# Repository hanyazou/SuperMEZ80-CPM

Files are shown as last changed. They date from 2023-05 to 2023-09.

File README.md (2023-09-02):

# SuperMEZ80-CPM
SuperMEZ80-CPM is a Z80 mezzanine board for simple single board computer EMUZ80.
SuperMEZ80-CPM adds SRAM and SPI micro SD Card slot to the EMUZ80.
With SuperMEZ80-CPM, you can run CP/M 2.2 and 3.0 disk images from the z80pack on the EMUZ80.

SuperMEZ80-CPM Features
  * Simple 3-chip configuration of Z80, SRAM and PIC
  * CP/M 3.0 banked memory can be used
  * A retro appearance, all chips are DIP, no surface-mounted components

SuperMEZ80-CPM is derived from satoshiokue's MEZ80RAM board.
Both EMUZ80 and MEZ80RAM are very interesting ideas.

SuperMEZ80-CPM is similar to the SuperMEZ80-SPI.
SuperMEZ80-CPM is simpler board with fewer components by removing I/O expander chip from SuperMEZ80-SPI.

## Appearance
The blue board in the following photo is SuperMEZ80-CPM and the red board is EMUZ80.





## Components you need

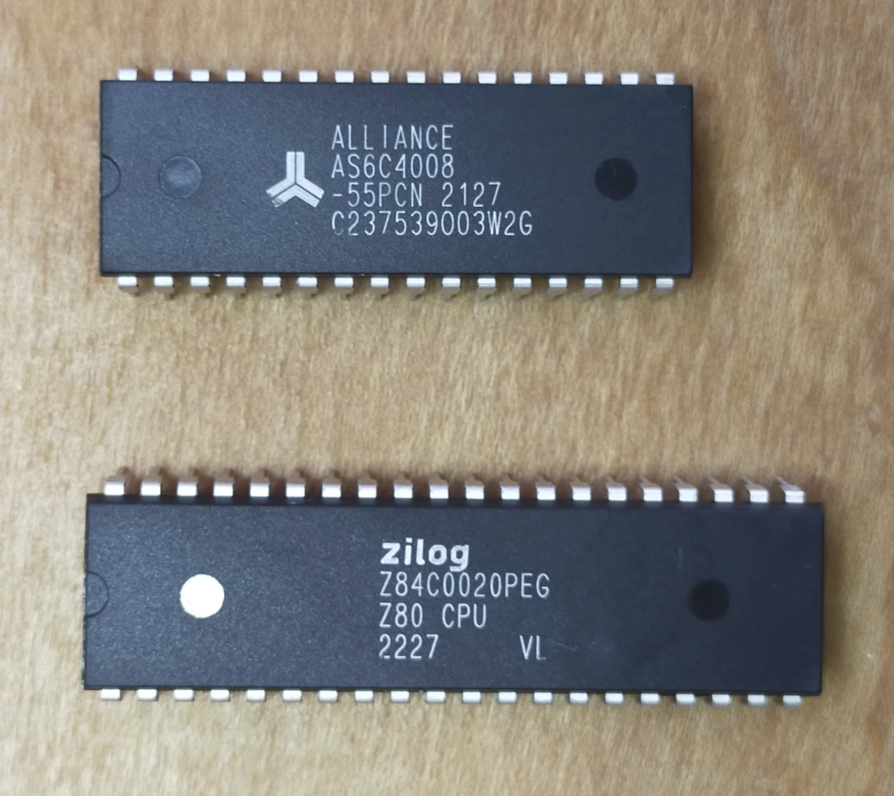
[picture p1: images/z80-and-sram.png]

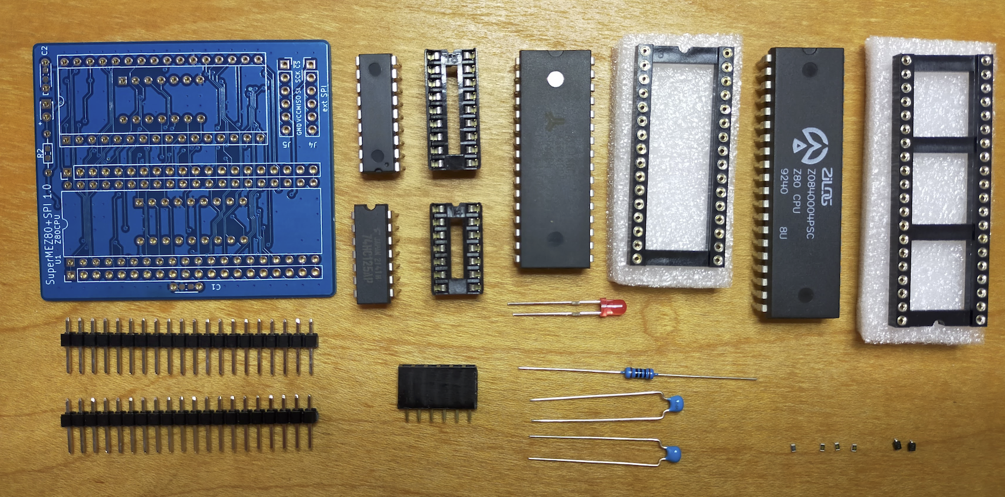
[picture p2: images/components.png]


### IC
  * 1 Z80 (DIP 40 pin) *1
  * 1 AS6C4008-55 SRAM 4Mbit (DIP 32 pin) *2
### Through hole components
  * 1 IC socket (DIP 40 pin)
  * 1 IC socket (DIP 32 pin)
  * 1 SD Card slot *3
  * 2 Capacitor 0.1uF
  * 3 LED
  * 3 Resistor 1.5K ohms 1/4W (the value of resistor will vary depending on the LED)
  * 1 Resistor array 10K ohms x8
  * 2 Pin header (0.1" pich 20x1 pin)
  * 1 Jumper cap and header (0.1" pich) *4
  * 1 Pin socket (0.1" pich 6x1 pin)

*1) Z80C0006 (6MHz) or higher are recomended

*2) 2Mbit (256KB) or more is required for CP/M 3.0.
CP/M 2.2 can still run with 512Kbit (64KB) or 1Mbit (128KB) RAM like TC551001.

*3) For the micro SD Card slot, use the one for Arduino as shown in the following page.

https://circuitdigest.com/microcontroller-projects/interfacing-micro-sd-card-module-with-arduino

*4) I use right angle pin header and jumper.
They are useful when I experiment external clock source. 
But you can omit them and just short RA3 - Z80 CLK with solder.

## Build Instructions

Due to some tall components, it is recommended to assemble them in the following order.

### Step 1: DIP 40 socket
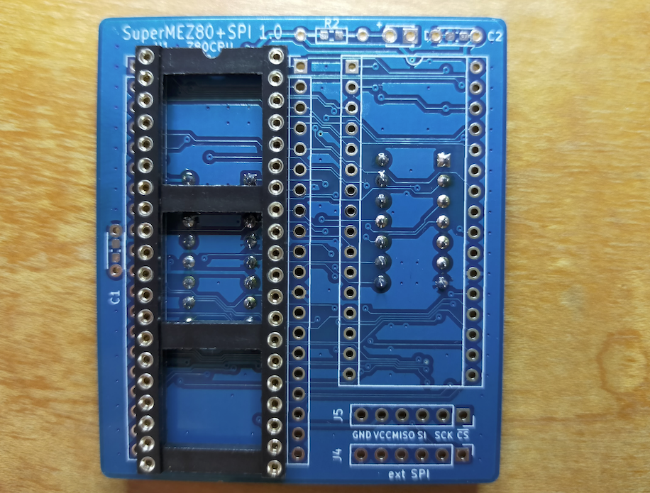
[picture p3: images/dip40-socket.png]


### Step 2: pin headers
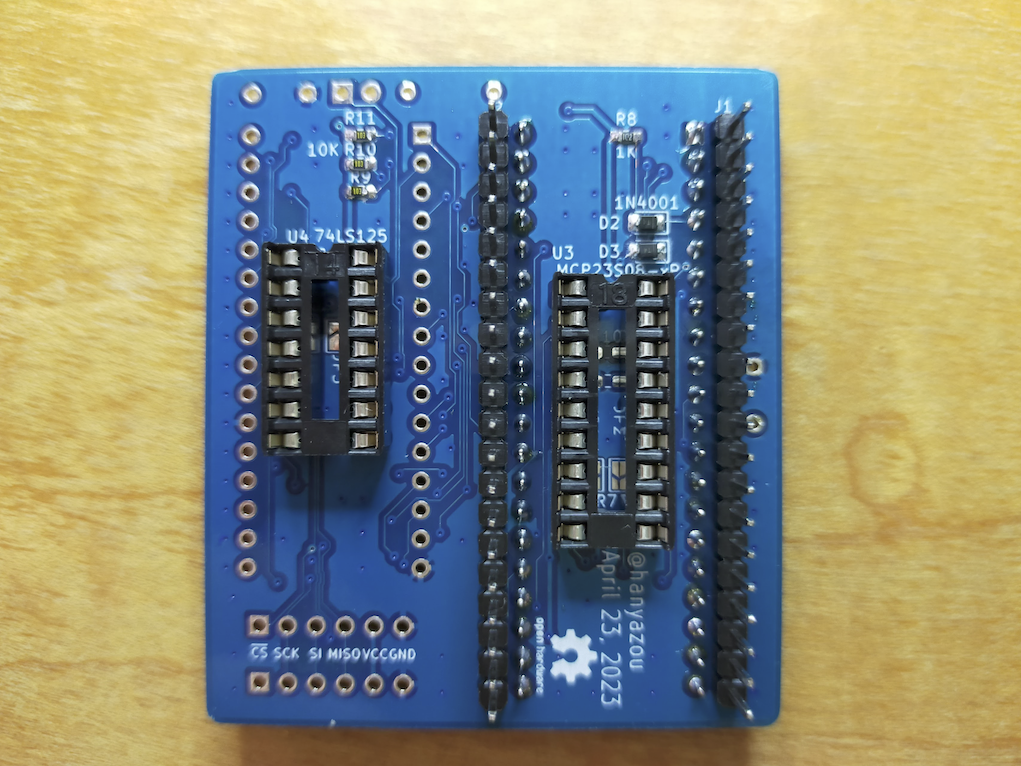
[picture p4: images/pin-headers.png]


### Step 3: LED and passive components


### Step 4: DIP 32 socket and 6 pin socket


## (Optional) SD card slot modification
SD Card slot component in the market may have a right angle pin header.
As it is, it might be little bit ugly as shown in the picture.



I de-soldered and replaced the header and mounted the SD card slot in back of SuperMEZ80-CPM.





You can also mount the SD Card slot on the top of the board like SuperMEZ-SPI.



## References
### SuperMEZ80 (derived version for SuperMEZ80-CPM)
Use this firmware to PIC on the EMUZ80 board.

https://github.com/hanyazou/SuperMEZ80

### EMUZ80
https://vintagechips.wordpress.com/2022/03/05/emuz80_reference/

### z80pack
https://github.com/udo-munk/z80pack

### MEZ80RAM
https://github.com/satoshiokue/MEZ80RAM

### SuperMEZ80 (Satoshi Okue's original FW for MEZ80RAM)
https://github.com/satoshiokue/SuperMEZ80

### SuperMEZ80-SPI
https://github.com/hanyazou/SuperMEZ80-SPI

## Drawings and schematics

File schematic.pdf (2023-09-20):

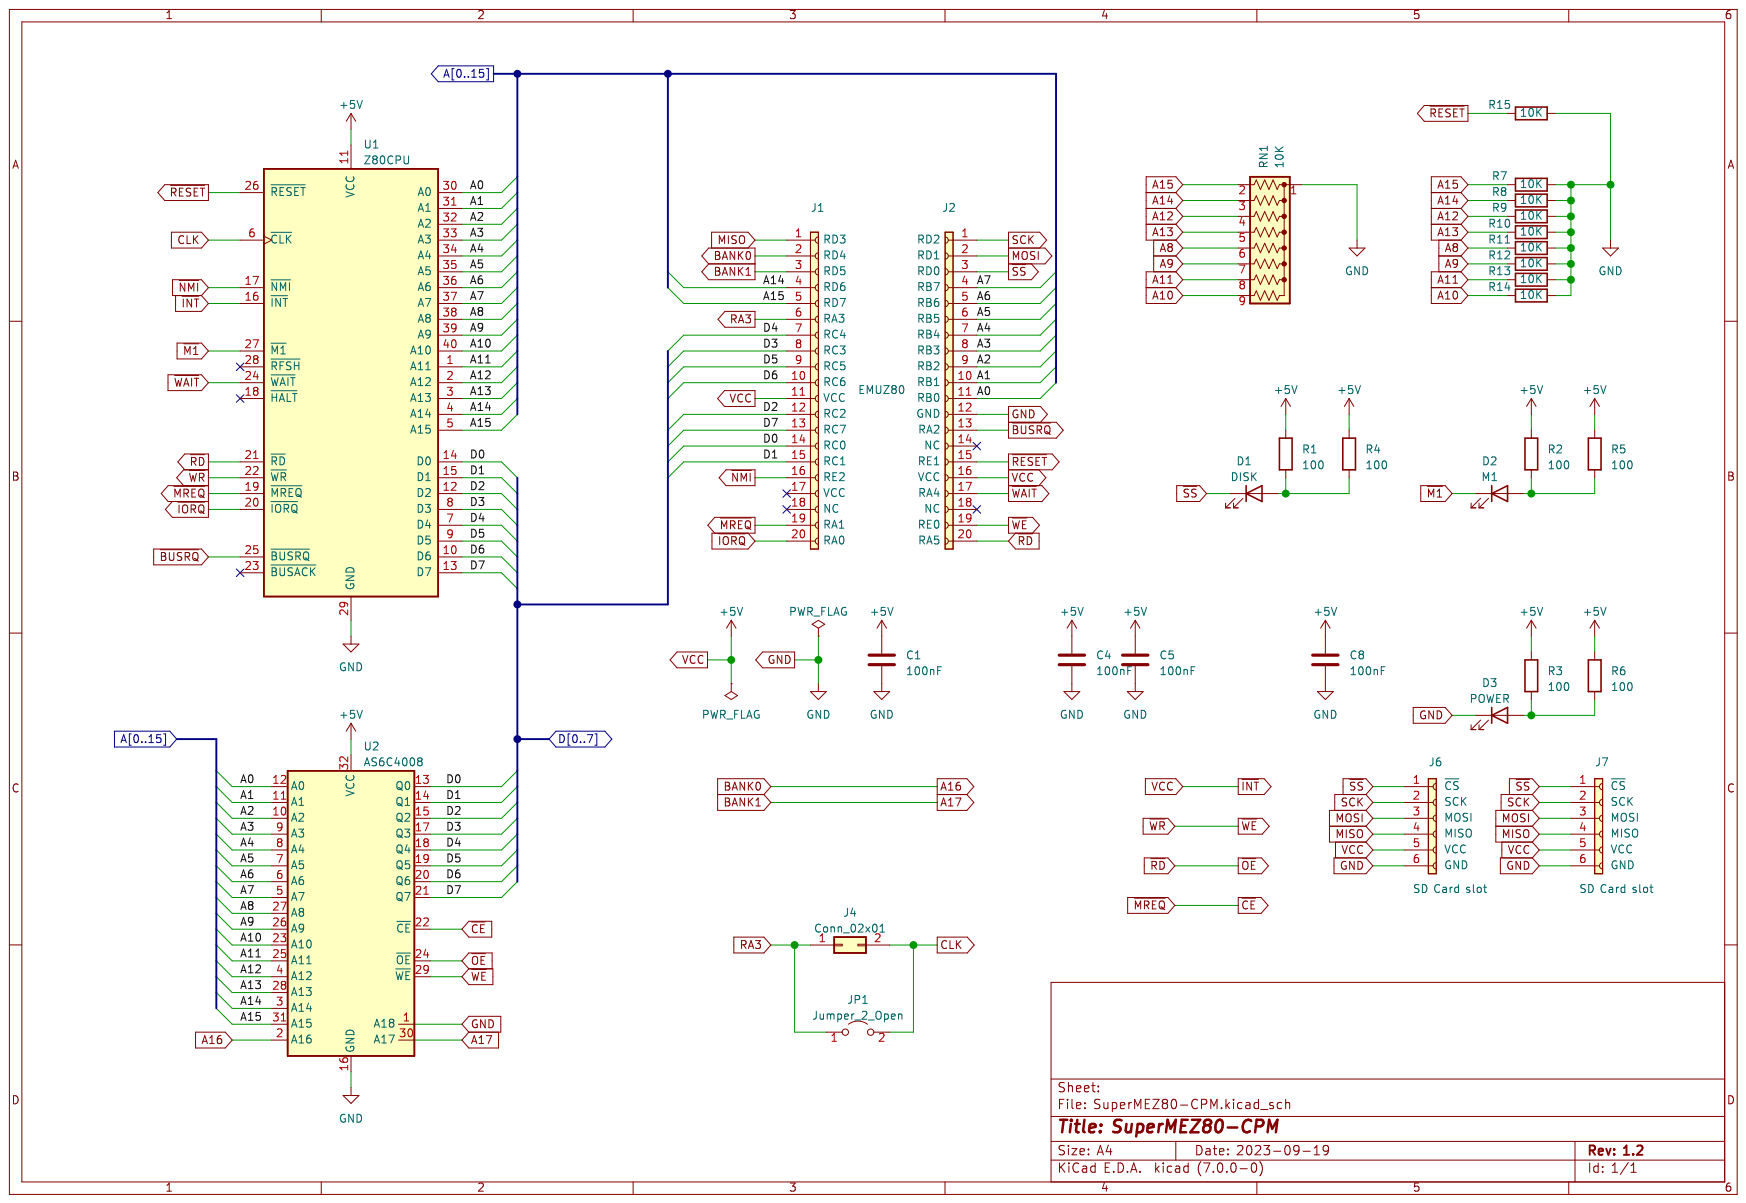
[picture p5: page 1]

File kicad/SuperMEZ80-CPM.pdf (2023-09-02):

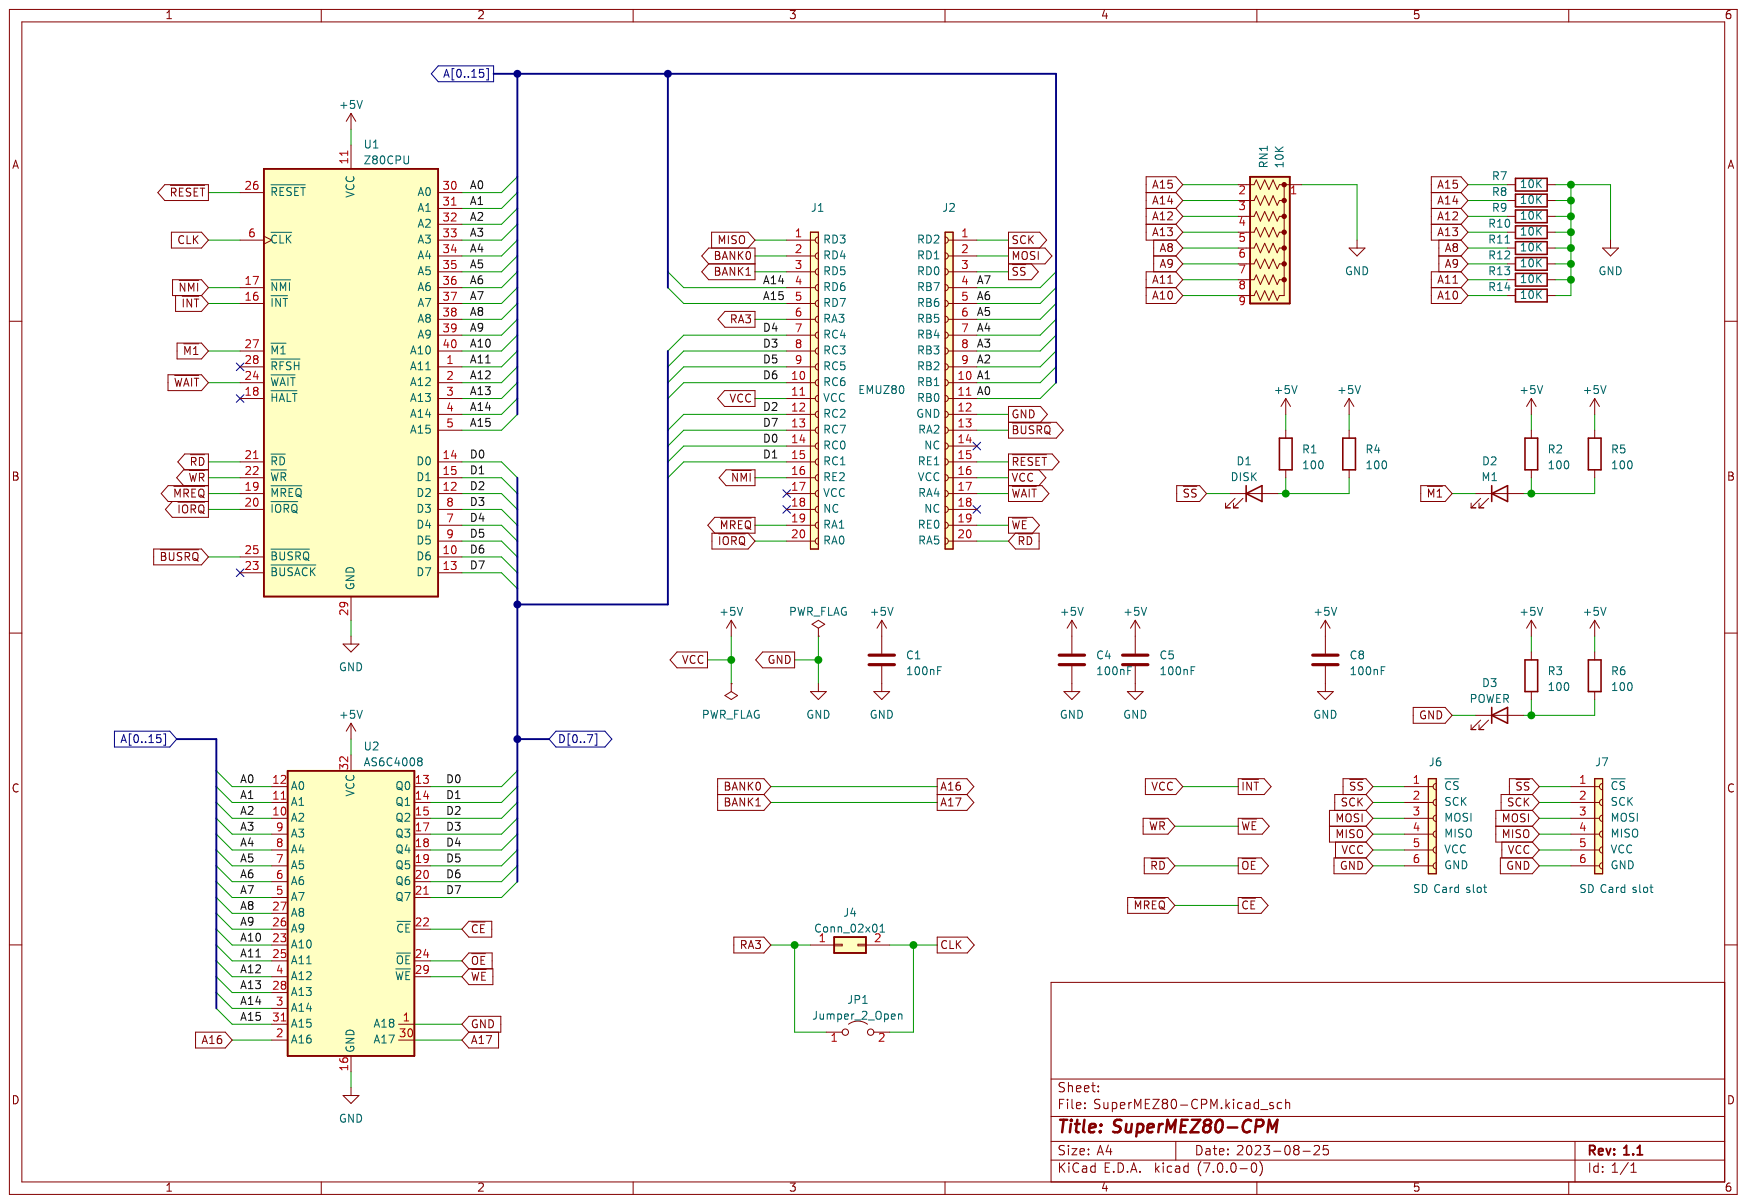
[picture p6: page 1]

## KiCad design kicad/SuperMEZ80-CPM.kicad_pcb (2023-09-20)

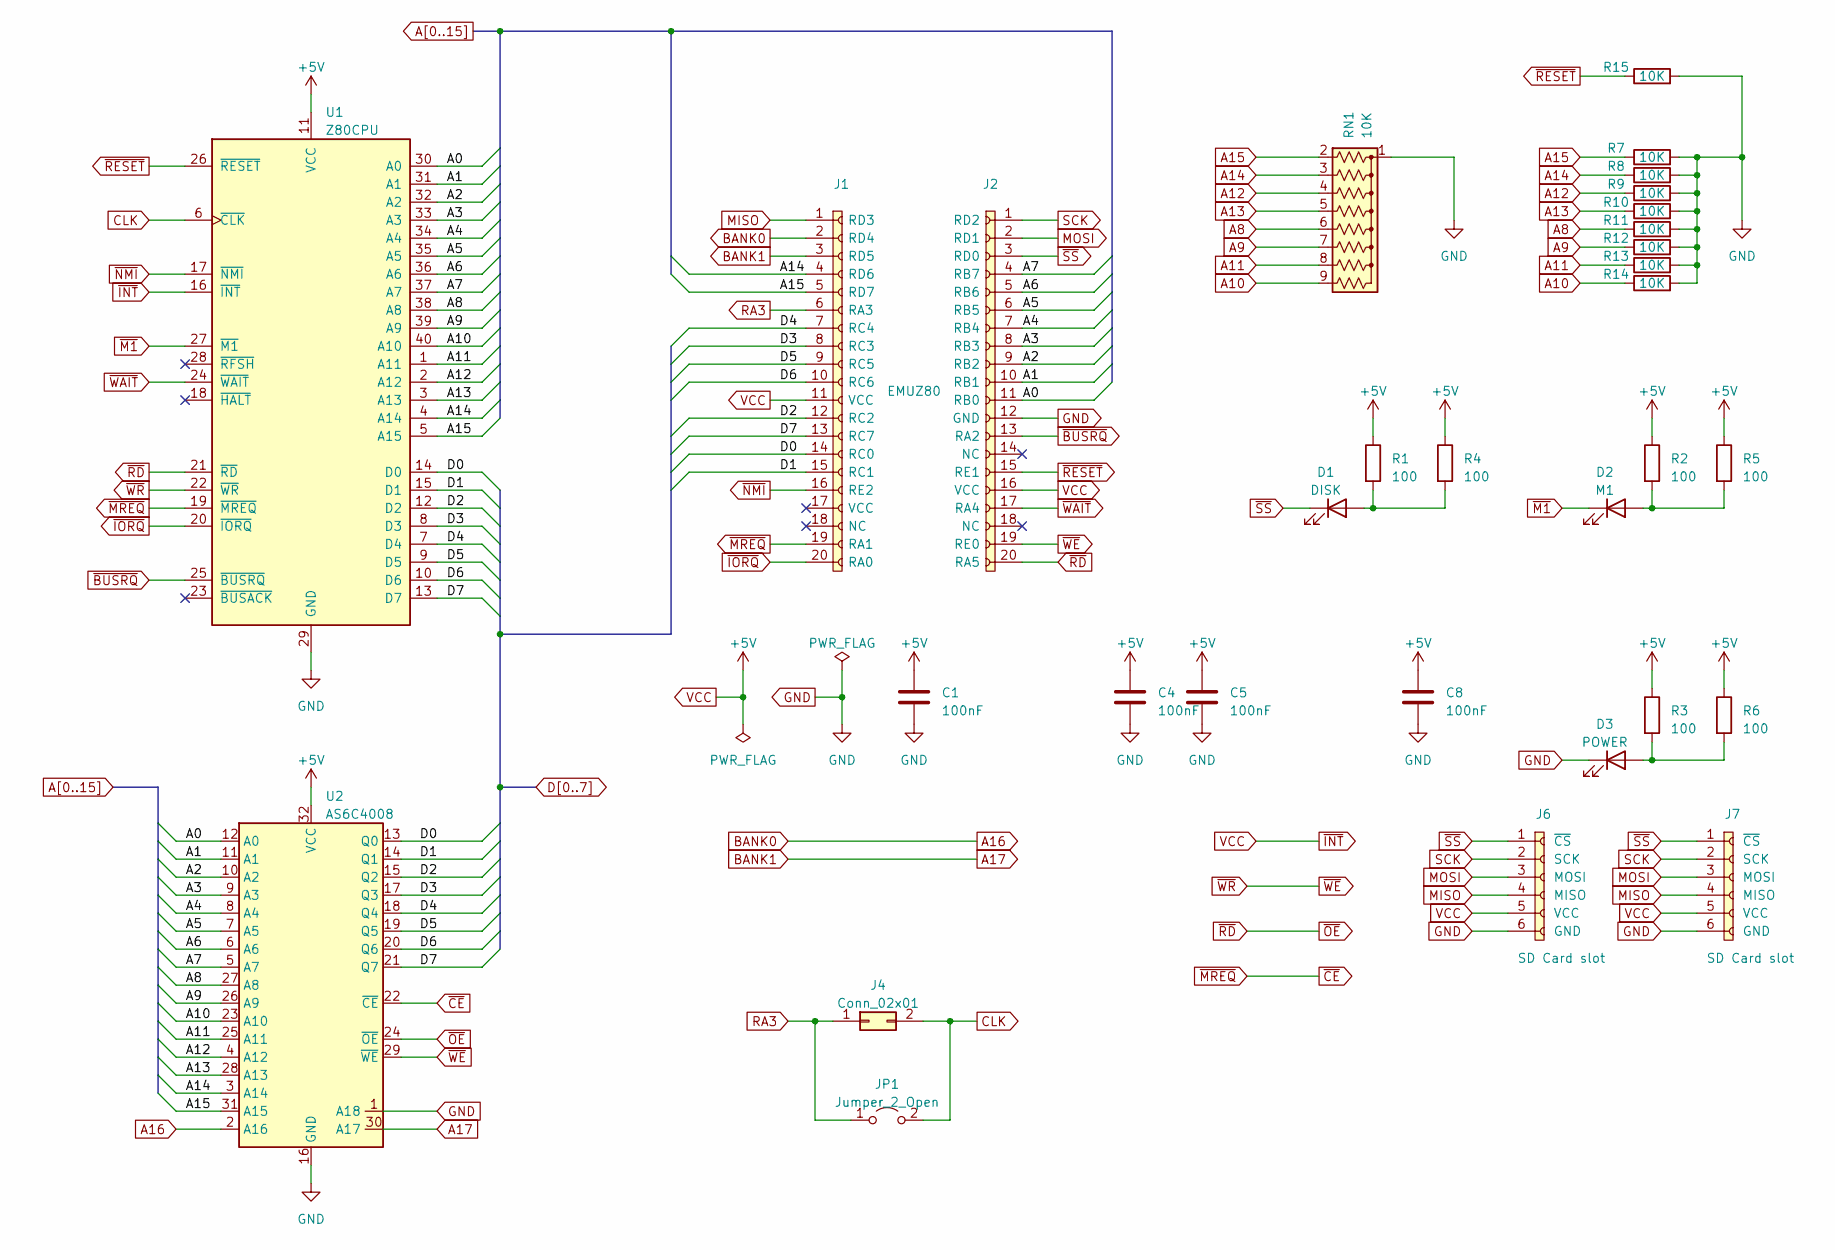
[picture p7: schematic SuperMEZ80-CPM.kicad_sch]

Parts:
C1, C4: 100nF; C_Disc_D4.3mm_W1.9mm_P5.00mm
C5, C8: 100nF; C_0603_1608Metric_Pad1.08x0.95mm_HandSolder
D1: DISK; LED_D1.8mm_W3.3mm_H2.4mm
D2: M1; LED_D1.8mm_W3.3mm_H2.4mm
D3: POWER; LED_D1.8mm_W3.3mm_H2.4mm
J1: EMUZ80_0; PinHeader_1x20_P2.54mm_Vertical
J2: EMUZ80; PinHeader_1x20_P2.54mm_Vertical
J4: Conn_02x01; PinHeader_1x02_P2.54mm_Vertical
J6, J7: SD Card slot; PinHeader_1x06_P2.54mm_Vertical
JP1: Jumper_2_Open; SolderJumper-2_P1.3mm_Open_RoundedPad1.0x1.5mm
R1, R2, R3: 100; R_Axial_DIN0204_L3.6mm_D1.6mm_P7.62mm_Horizontal
R4, R5, R6: 100; R_0603_1608Metric_Pad0.98x0.95mm_HandSolder
R7, R8, R9, R10, R11, R12, R13, R14, R15: 10K; R_0603_1608Metric_Pad0.98x0.95mm_HandSolder
RN1: 10K; R_Array_SIP9
U1: Z80CPU; DIP-40_W15.24mm
U2: AS6C4008; DIP-32_W15.24mm_Socket

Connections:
A0: J2.11 (RB0), U1.30 (A0), U2.12 (A0)
A1: J2.10 (RB1), U1.31 (A1), U2.11 (A1)
A2: J2.9 (RB2), U1.32 (A2), U2.10 (A2)
A3: J2.8 (RB3), U1.33 (A3), U2.9 (A3)
A4: J2.7 (RB4), U1.34 (A4), U2.8 (A4)
A5: J2.6 (RB5), U1.35 (A5), U2.7 (A5)
A6: J2.5 (RB6), U1.36 (A6), U2.6 (A6)
A7: J2.4 (RB7), U1.37 (A7), U2.5 (A7)
A8: R11.1, RN1.6 (R5), U1.38 (A8), U2.27 (A8)
A9: R12.1, RN1.7 (R6), U1.39 (A9), U2.26 (A9)
A10: R14.1, RN1.9 (R8), U1.40 (A10), U2.23 (A10)
A11: R13.1, RN1.8 (R7), U1.1 (A11), U2.25 (A11)
A12: R9.1, RN1.4 (R3), U1.2 (A12), U2.4 (A12)
A13: R10.1, RN1.5 (R4), U1.3 (A13), U2.28 (A13)
A14: J1.4 (RD6), R8.1, RN1.3 (R2), U1.4 (A14), U2.3 (A14)
A15: J1.5 (RD7), R7.1, RN1.2 (R1), U1.5 (A15), U2.31 (A15)
A16: J1.2 (RD4), U2.2 (A16)
A17: J1.3 (RD5), U2.30 (A17)
CLK: J4.2, JP1.2 (B), U1.6 (~CLK)
D0: J1.14 (RC0), U1.14 (D0), U2.13 (Q0)
D1: J1.15 (RC1), U1.15 (D1), U2.14 (Q1)
D2: J1.12 (RC2), U1.12 (D2), U2.15 (Q2)
D3: J1.8 (RC3), U1.8 (D3), U2.17 (Q3)
D4: J1.7 (RC4), U1.7 (D4), U2.18 (Q4)
D5: J1.9 (RC5), U1.9 (D5), U2.19 (Q5)
D6: J1.10 (RC6), U1.10 (D6), U2.20 (Q6)
D7: J1.13 (RC7), U1.13 (D7), U2.21 (Q7)
GND: C1.2, C4.2, C5.2, C8.2, D3.1 (K), J2.12 (GND), J6.6 (GND), J7.6 (GND), R7.2, R8.2, R9.2, R10.2, R11.2, R12.2, R13.2, R14.2, R15.2, RN1.1 (common), U1.29 (GND), U2.1 (A18), U2.16 (GND)
MISO: J1.1 (RD3), J6.4 (MISO), J7.4 (MISO)
MOSI: J2.2 (RD1), J6.3 (MOSI), J7.3 (MOSI)
unnamed: D1.2 (A), R1.2, R4.2
unnamed: D2.2 (A), R2.2, R5.2
unnamed: D3.2 (A), R3.2, R6.2
RA3: J1.6 (RA3), J4.1, JP1.1 (A)
SCK: J2.1 (RD2), J6.2 (SCK), J7.2 (SCK)
VCC: C1.1, C4.1, C5.1, C8.1, J1.11 (VCC), J2.16 (VCC), J6.5 (VCC), J7.5 (VCC), R1.1, R2.1, R3.1, R4.1, R5.1, R6.1, U1.11 (VCC), U1.16 (~INT), U2.32 (VCC)
~BUSRQ: J2.13 (RA2), U1.25 (~BUSRQ)
~CE: J1.19 (RA1), U1.19 (~MREQ), U2.22 (~CE)
~IORQ: J1.20 (RA0), U1.20 (~IORQ)
~M1: D2.1 (K), U1.27 (~M1)
~NMI: J1.16 (RE2), U1.17 (~NMI)
~OE: J2.20 (RA5), U1.21 (~RD), U2.24 (~OE)
~RESET: J2.15 (RE1), R15.1, U1.26 (~RESET)
~SS: D1.1 (K), J2.3 (RD0), J6.1 (~CS), J7.1 (~CS)
~WAIT: J2.17 (RA4), U1.24 (~WAIT)
~WE: J2.19 (RE0), U1.22 (~WR), U2.29 (~WE)

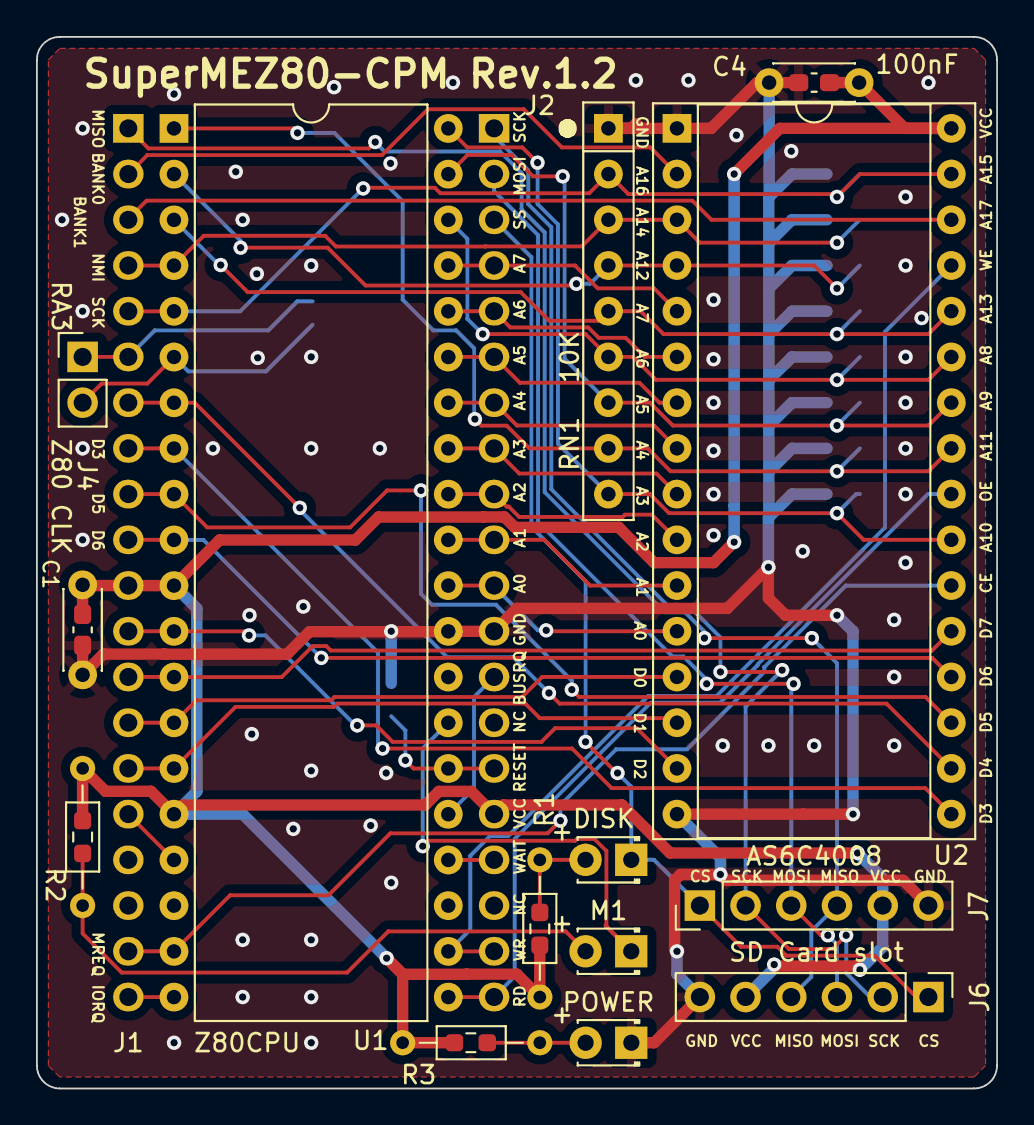
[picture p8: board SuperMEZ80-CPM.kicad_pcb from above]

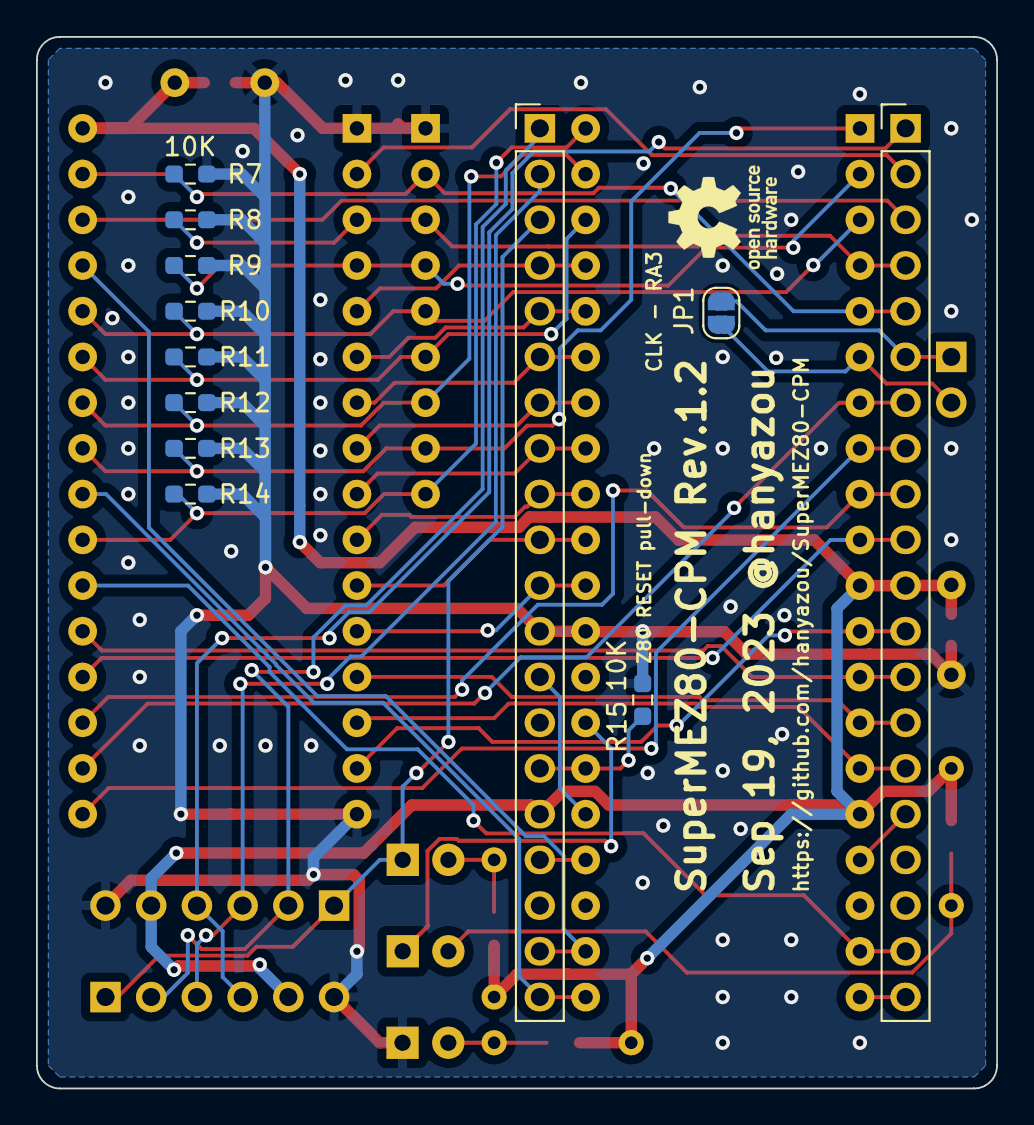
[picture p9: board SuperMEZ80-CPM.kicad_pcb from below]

Board: 2 copper layers, 53.3 x 58.4 mm, 31 parts (12 on the bottom side), 46 nets.

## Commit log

2023-05-01 Add SuperMEZ80+SPI 1.0
    [MEZ80RAM-SD.kicad_pcb, MEZ80RAM-SD.kicad_sch, untitled.kicad_sch]
2023-05-06 Fix LED registor value, diode type and so on
2023-07-09 Add first version of SuperMEZ80-CPM PCB
    [MEZ80RAM-SD.kicad_pcb, SuperMEZ80-CPM.kicad_pcb, SuperMEZ80-CPM.kicad_sch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]
2023-08-17 Add SuperMEZ80-CPM version 1.0
    [SuperMEZ80-CPM.kicad_pcb, SuperMEZ80-CPM.kicad_sch]
2023-09-02 Add SuperMEZ80-CPM version 1.1 and update README.md
    [SuperMEZ80-CPM.kicad_pcb, SuperMEZ80-CPM.kicad_sch]
2023-09-20 Add SuperMEZ80-CPM version 1.2
    [SuperMEZ80-CPM.kicad_pcb, SuperMEZ80-CPM.kicad_sch]
